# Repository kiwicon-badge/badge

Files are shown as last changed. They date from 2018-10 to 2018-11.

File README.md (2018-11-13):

# Kiwicon Intro to Badge Hacking

This repo is to host the instructions and code for the Kiwicon 2038 Intro to Badge Hacking course (https://www.kiwicon.org/the-con/training/intro-to-badge-hacking/).

## Welcome!

First up, welcome to the course :D

I hope that today is enjoyable and that you leave having gained skills and knowledge you can put to good use.

Learning the basics of electronics is a great skill. You may use this in the future to deconstructe IOT devices, build your own tools, or simply to fix a broken gadget. When combined with basic programming skills, this can take on a whole new level, where your imagination and, usually more importantly, budget are the only limits!

In particular, learning about how microcontrollers work is a great asset. This gives you the fundamentals for learning about more complex computers and systems. Note that, these days, a computer isn't really a single entity, it is a whole ecosystem of various smaller microcontrollers doing all sorts of functions. Your laptops itself likely has several dozen 'computers' in it, the CPU, GPU, controllers for the keyboard, touchpad, webcam, touchbar, SSD, Wi-Fi, Bluetooth... not to mention dongles. It's a great time to get a better understanding of how all these components can interact, particularly in light of recent events!

There is no fixed timeline to today. I have broken everything down into labs which we will move through, but feel free to go at your own pace! The only aim that I have for you today is to leave with a completed, working badge. So take time to make sure you understand everything and get the most out of it. If you race through everything, take the time to help out those around you or come up with some new idea you can program the badge to do, it's up to you.

Happy hacking!

## Safety / Conduct

+ In the event of a fire, leave all your gear and follow the exit signs out of the building.
+ In the event of an earthquake, go under your table. When the shaking stops, egress the building following the exit signs, and move to clear ground (up near parliament).
+ We will be working with toxic elements, i.e. lead (PB), in the solder. Do not ingest the solder and make sure you wash your hands before eating anything.
+ The solder flux may be irritating to some. If you have an issue, move to one of the tables / stations nearer the windows.
+ Soldering irons are hot! Always beware where you are putting it and make sure the cord is in a safe location where noone can trip over it.
+ If you see any hazards, let me know and we will work to minimise or remedy these.
+ We follow the [Kiwicon Code of Conduct](https://www.kiwicon.org/faq/#q9). Don't be a shitweasel! We're here to learn in a collaborative environment. Leave everything else at the door.

## Breaks / Facilities

+ Please note this is a working environment. Please keep noise down outside the conference room!
+ There is cans of Sprite in the fridge, water in the tap.
+ Toilets are in the stairwells, female toilets are to the left just outside the door, males to the left on the other side of the single lift. Ask for an access card before you leave, as the stairwell doors are locked. If you get locked out without a card, go to the ground floor and take the lift back up to level 4.
+ We will take regular breaks, but if you have something to do, feel free to bounce in and out as needed.

## Course Labs

+ Electrical Circuits - https://github.com/kiwicon-badge/badge/tree/master/lab-01
+ Microcontrollers - https://github.com/kiwicon-badge/badge/tree/master/lab-02
+ Loading a Program - https://github.com/kiwicon-badge/badge/tree/master/lab-03
+ Soldering - https://github.com/kiwicon-badge/badge/tree/master/lab-04
+ Badge Assembly - https://github.com/kiwicon-badge/badge/tree/master/lab-05
+ Badge Programming / Hacking - https://github.com/kiwicon-badge/badge/tree/master/lab-06

After that, if anyone is interested, we can run through PCB design using Eagle (and maybe Fritzing).

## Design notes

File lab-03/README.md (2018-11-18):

## Loading a Program

The Attiny13a is a fairly limited device, with only 1024 bytes of flash storage in which to store your program, and 64 bytes of RAM (it also has 64 bytes of EEPROM, but we won't be using that today). However, it is still a great platform to learn with and, as a quick web search shows, what you can do with it may only limited by your imagination.

In this lab, we will run through how to use the Arduino IDE and the USBAsp programmer to create and upload new code to the device. (If we're running on schedule, we'll also use the command line tools available.)

Annoyingly, USBAsp devices number their pins different to what is used on microcontrollers (this caused me a LOT of frustration at one point). Instead of starting on one side and going around, the pinouts jump from side to side:
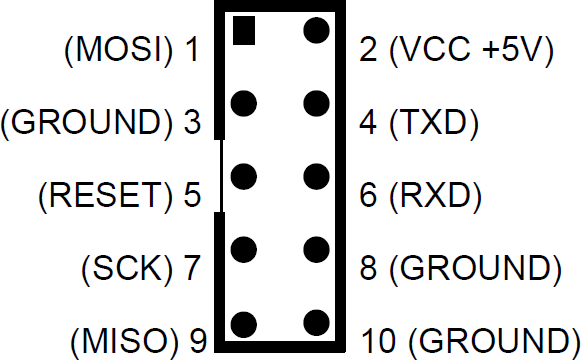
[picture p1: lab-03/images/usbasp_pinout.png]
USBAsp pinouts


Make sure you use the above pinouts!

### Tools

| Item &nbsp; &nbsp; &nbsp; &nbsp; &nbsp; &nbsp; &nbsp; &nbsp; &nbsp; &nbsp; &nbsp; &nbsp; &nbsp; &nbsp; &nbsp;&nbsp; &nbsp; &nbsp; &nbsp; &nbsp; &nbsp; &nbsp; &nbsp; &nbsp; &nbsp; &nbsp; &nbsp; &nbsp; &nbsp; | &nbsp; &nbsp; &nbsp; &nbsp; Count |
| --- |---:|
| USBAsp programmer | x1 |
| Female to male jumper wires | x6 |
| Laptop, with Arduino installed | x1 |
| Breadboard setup from Lab-02 | x1 |

### Instructions

0. Make sure you have your breadboard setup as per [Lab-02](https://github.com/kiwicon-badge/badge/blob/master/lab-02/README.md). Remove the battery and set it aside.
1. Make sure your Arduino IDE is installed. If you are on windows, install the drivers for the USBAsp ([download here](https://protostack.com.au/2015/01/usbasp-windows-driver-version-3-0-7/)).
2. Open the IDE settings (File->Settings) and paste the URL below in “Additional URLs for the board manager”, then click “OK”:
https://mcudude.github.io/MicroCore/package_MCUdude_MicroCore_index.json
3. Open the Boards manager (Tools->Board->Boards manager), search for and install the “MicroCore” package. This will enable programming the ATtiny13a microcontroller.
4. In tools, select the right options. Board: “ATtiny13”; Clock: “1.2MHz internal oscillator”; BOD: “Disabled”; Complier LTO: "Disabled".
5. In tools, select the "USBAsp" programmer.
6. Connect the programmer to your breadboard as per below:

7. In tools hit Burn the bootloader (actually it's not a true bootloader, just AVR fuses), you should see some LEDs flashing, if you don't encounter any problem you can go ahead.
8. Download the ["Blinky lights"](https://raw.githubusercontent.com/kiwicon-badge/badge/master/lab-03/files/attiny13a_blink.ino) sketch.
9. Upload this to the badge (Sketch -> Upload). While uploading the sketch, you should see some LEDs flashing. If the Arduino IDE doesn't throw any error you can go ahead, else ask for help.
10. The breadboard should now be drawing power via the USBAsp, so the microcontroller should be powered up and start the sketch.
11. Use the Arduino IDE to change the timeouts (i.e. the "delay(500)" wait instruction) and reupload your code to see the changes take effect.
12. Disconnect the jumpers to the USBAsp and plug in the battery.

### Additional Resources
+ https://quadmeup.com/programming-attiny85-and-attiny45-with-arduino-ide/
+ USBAsp drivers for Windows (should work on Win10) - https://protostack.com.au/2015/01/usbasp-windows-driver-version-3-0-7/

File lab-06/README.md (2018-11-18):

## Programming Your Badge

Similar to the earlier lab, you will now program the badge!

Use the following pinout when connecting the USBAsp to the badge:

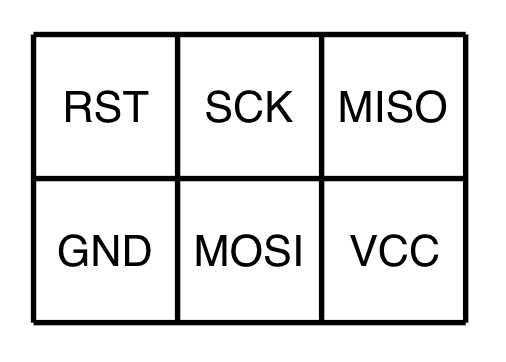
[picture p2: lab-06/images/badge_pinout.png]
USBAsp pinouts


Once final complication is that the badge uses a feature that is called "charlieplexing". As a microcontroller can have three states - input, output, and high impedance - designers can leverage this and the property of LEDs - that current can only flow forward through the component - to make up for the fact that they only have a limited number of pins. For example, the following schematic shows how to control 6 LEDs with only 3 pins:

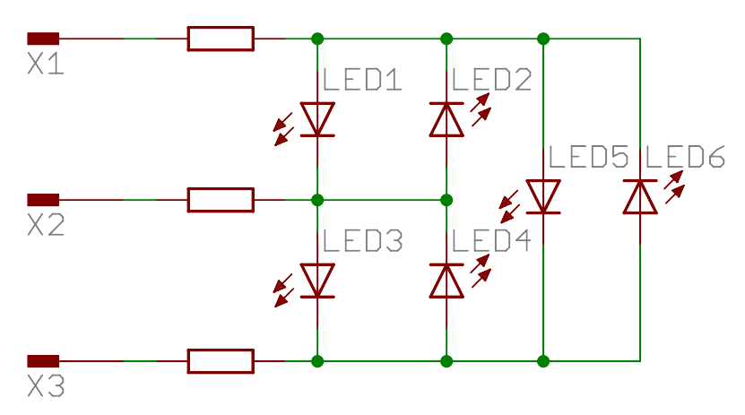
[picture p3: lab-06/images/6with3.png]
Charlieplexing


(*Rather than using charlieplexing, you can also use additional components. I have some shift registers here, which you can breadboard with if you choose.*)

In this case, the badge uses only 5 pins to control 20 LEDs individually.

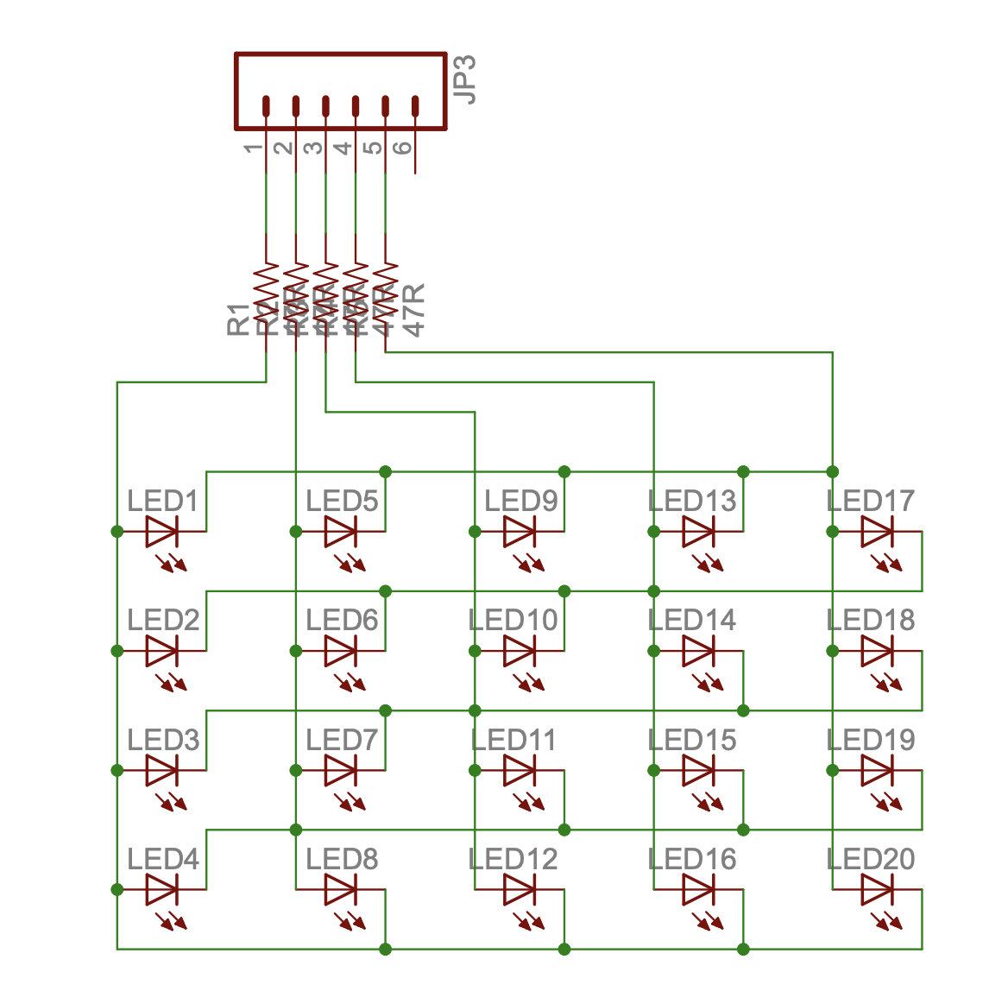
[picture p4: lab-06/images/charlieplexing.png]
Badge Charlieplexing


This means that to turn on a specific LED, you have to follow the below table:

| LED (ROW/COLUMN) | HIGH PIN | LOW PIN&nbsp; |
| ---|--:|--:|
| R1/C1 | 4 | 0 |
| R1/C2 | 3 | 0 |
| R1/C3 | 2 | 0 |
| R1/C4 | 1 | 0 |
| R2/C1 | 4 | 1 |
| R2/C2 | 3 | 1 |
| R2/C3 | 2 | 1 |
| R2/C4 | 0 | 1 |
| R3/C1 | 4 | 2 |
| R3/C2 | 3 | 2 |
| R3/C3 | 1 | 2 |
| R3/C4 | 0 | 2 |
| R4/C1 | 4 | 3 |
| R4/C2 | 2 | 3 |
| R4/C3 | 1 | 3 |
| R4/C3 | 0 | 3 |
| R5/C1 | 3 | 4 |
| R5/C2 | 2 | 4 |
| R5/C3 | 1 | 4 |
| R5/C4 | 0 | 4 |

### Tools

| Item &nbsp; &nbsp; &nbsp; &nbsp; &nbsp; &nbsp; &nbsp; &nbsp; &nbsp; &nbsp; &nbsp; &nbsp; &nbsp; &nbsp; &nbsp;&nbsp; &nbsp; &nbsp; &nbsp; &nbsp; &nbsp; &nbsp; &nbsp; &nbsp; &nbsp; &nbsp; &nbsp; &nbsp; &nbsp; | &nbsp; &nbsp; &nbsp; &nbsp; Count |
| --- |---:|
| USBAsp programmer | x1 |
| Female to male jumper wires | x6 |
| Laptop, with Arduino installed | x1 |
| Completed badge | x1 |

### Instructions

1. Remove the battery from your badge.
2. Grab the [basic code](https://raw.githubusercontent.com/kiwicon-badge/badge/master/lab-03/files/attiny13a_blink.ino) sketch.
3. Open this in your Arduino IDE, and upload this to the badge (Sketch -> Upload). While uploading the sketch, you should see some LEDs flashing. If the Arduino IDE doesn't throw any error you can go ahead, else ask for help.
4. The breadboard should now be drawing power via the USBAsp, so the microcontroller should be powered up and start the sketch.

From here on is hacking time! Come up with some new ideas and see what you can create!

### Additional Resources
+ https://en.wikipedia.org/wiki/Charlieplexing
+ lucstechblog Charlieplexing series - http://lucstechblog.blogspot.com/2017/09/charlieplexing.html

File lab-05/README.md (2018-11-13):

## Badge Assembly
The fun bit! Now you have the skills, we're going to put them all together to construct something useful. Take your time and make sure you get it right, less speed is more haste when it comes to assembly!

### Tools

| Item &nbsp; &nbsp; &nbsp; &nbsp; &nbsp; &nbsp; &nbsp; &nbsp; &nbsp; &nbsp; &nbsp; &nbsp; &nbsp; &nbsp; &nbsp;&nbsp; &nbsp; &nbsp; &nbsp; &nbsp; &nbsp; &nbsp; &nbsp; &nbsp; &nbsp; &nbsp; &nbsp; &nbsp; &nbsp; | &nbsp; &nbsp; &nbsp; &nbsp; Count |
| --- |---:|
| Soldering iron kit (wand, cradle, brass sponge) | x1 |
| Multimeter | Shared |
| Flush cutters | x1 |

### Components

| Item &nbsp; &nbsp; &nbsp; &nbsp; &nbsp; &nbsp; &nbsp; &nbsp; &nbsp; &nbsp; &nbsp; &nbsp; &nbsp; &nbsp; &nbsp;&nbsp; &nbsp; &nbsp; &nbsp; &nbsp; &nbsp; &nbsp; &nbsp; &nbsp; &nbsp; &nbsp; &nbsp; &nbsp; &nbsp; | &nbsp; &nbsp; &nbsp; &nbsp; Count |
| --- |---:|
| Badge PCB | x1 |
| Coin cell battery holder | x1 |
| Headers, male (pin) | x9 |
| Jumper | x1 |
| 100 Ohm resistor | x5 |
| Green LED | x20 |
| Solder | x1 |
| Resistor / Solid core wire | x10 |

### Instructions

You have a choice here. So far, you have practiced Through-Hole Soldering (THT), whereas the microcontroller used on the badge is an Surface Mount (SMD) component. This is somewhat trickier to solder successfully without a bit of practice! Let me know if you are game to give it a go, else I can do it for you and let you get on with the rest of the badge.

Either way, make sure your iron is nice and hot and that all your components are ready!

1. Pick up a resistor and bend the lead wires to each side of the body of the component until they are at 90 degrees to the main body, then insert this into the holes as per the image below, and press the body of the resistor until it is firmly against the front face of the PCB, then using your other hand bend the legs of the resistor outwards to hold it in place.
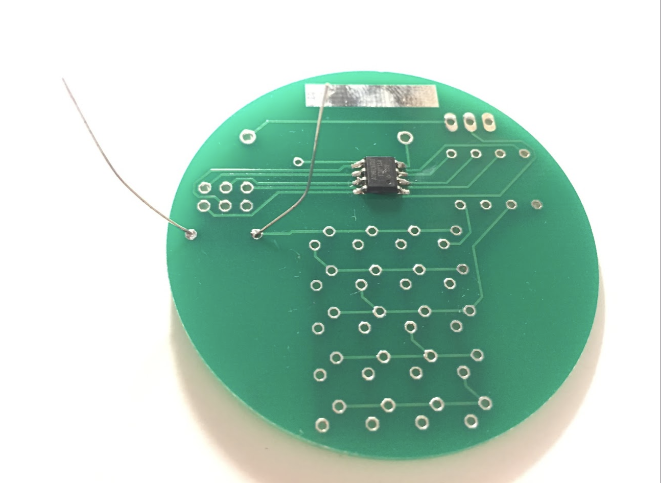
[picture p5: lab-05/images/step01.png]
First resistor

2. Solder both legs of the resistor into place.
3. Snip off the legs, about 1-1.5mm from the PCB.
4. Repeat step 1 for the next four resistors and insert them as per the image below:
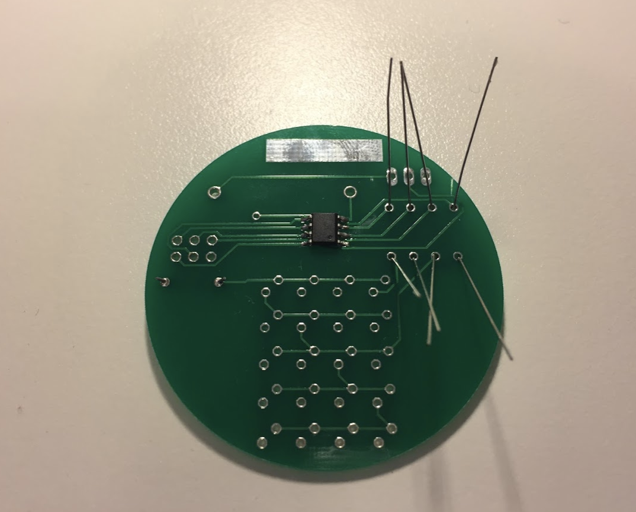
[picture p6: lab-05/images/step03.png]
Remaining resistors

5. Solder these into place and snip of the legs as per step 3.
6. Next, you will start inserting the LEDs. It is CRITICAL that you make sure that you always, always, always insert the LED legs so that the short leg (cathode / negative) is closest to the dot on the front of the PCB, as per the image below:
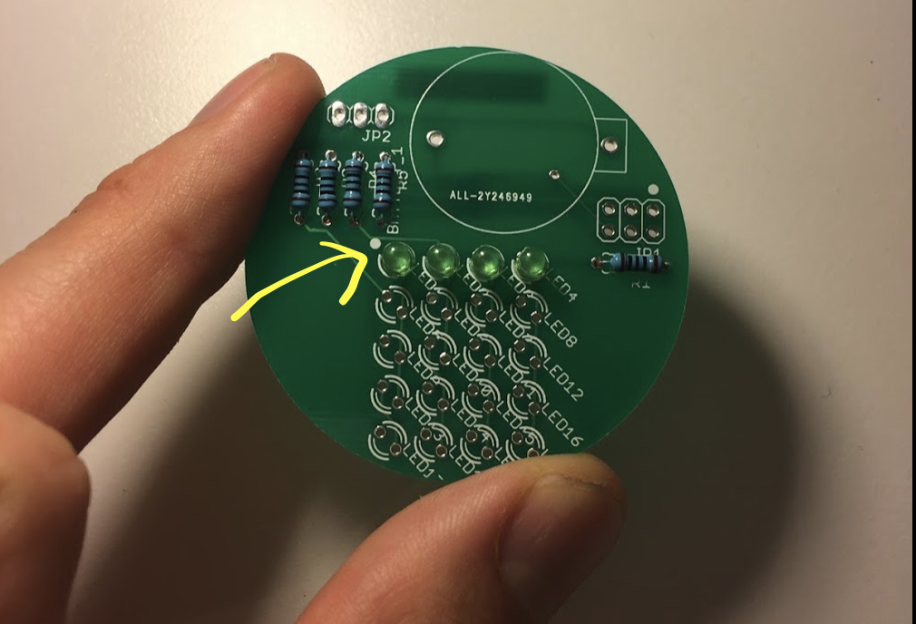
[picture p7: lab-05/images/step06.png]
Cathode dot

7. You can either insert on LED at a time (probably a good idea to start with) or insert a whole row at a time, but either way, always double check you have your LEDs oriented the correct way. Bend the legs and solder into place.
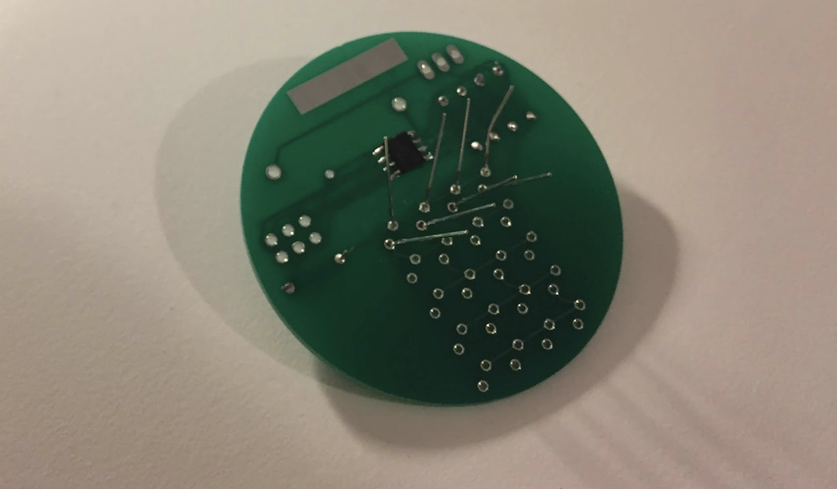
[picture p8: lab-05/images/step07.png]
Inserting LEDs

8. Once you have done a row of LEDs, give me a call to check it out. If it all looks like the below and I am happy, carry on!
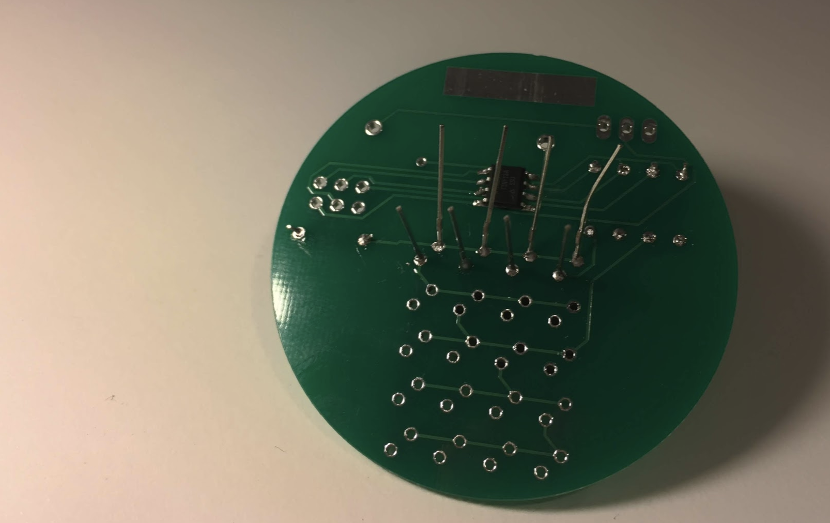
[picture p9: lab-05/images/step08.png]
Check LEDs

9. Next, you will solder in the header pins. These are a bit tricky, as you cannot simply bend the legs. If there is some bluetac handy, you can use a bit of this to hold them in place while you solder them. First do the two rows of three header pins, then do the single row of three.
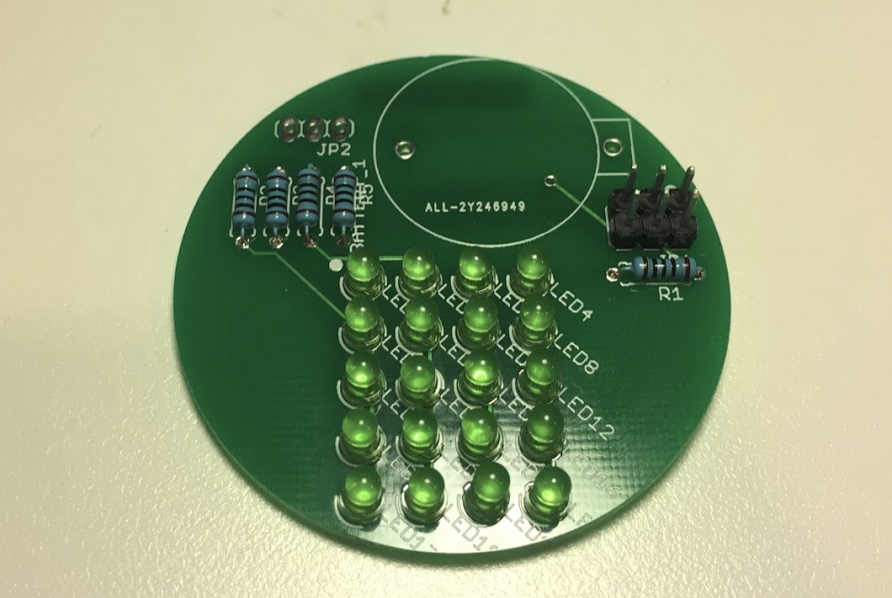
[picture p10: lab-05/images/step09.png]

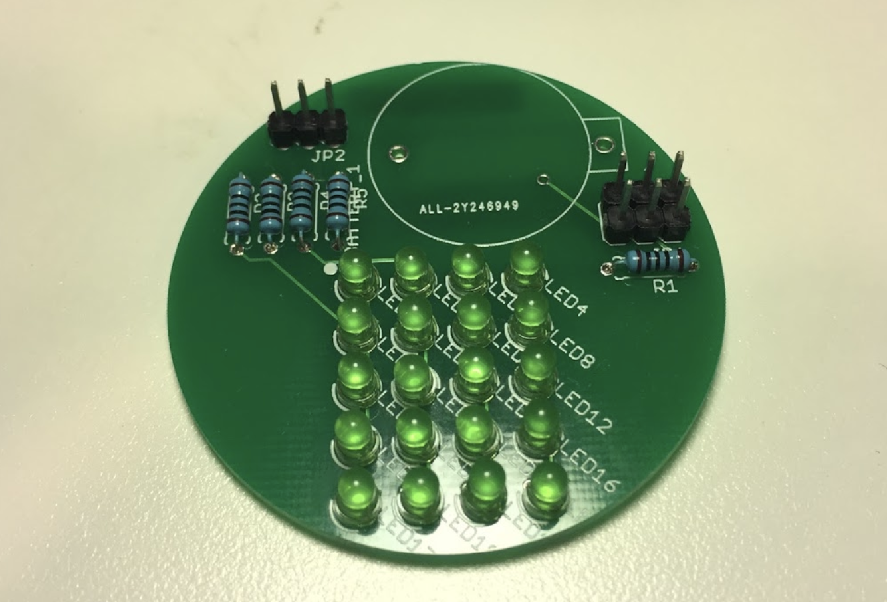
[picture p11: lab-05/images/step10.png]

10. Similar to the header pins, the battery holder is a bit fiddly. Use some bluetac to hold it in place if it is available. If not, you will get there ;) The pins are a bit larger, so may take a bit more heat. Try putting the soldering iron on the holder pins for a bit before you then also touch the PCB pads.
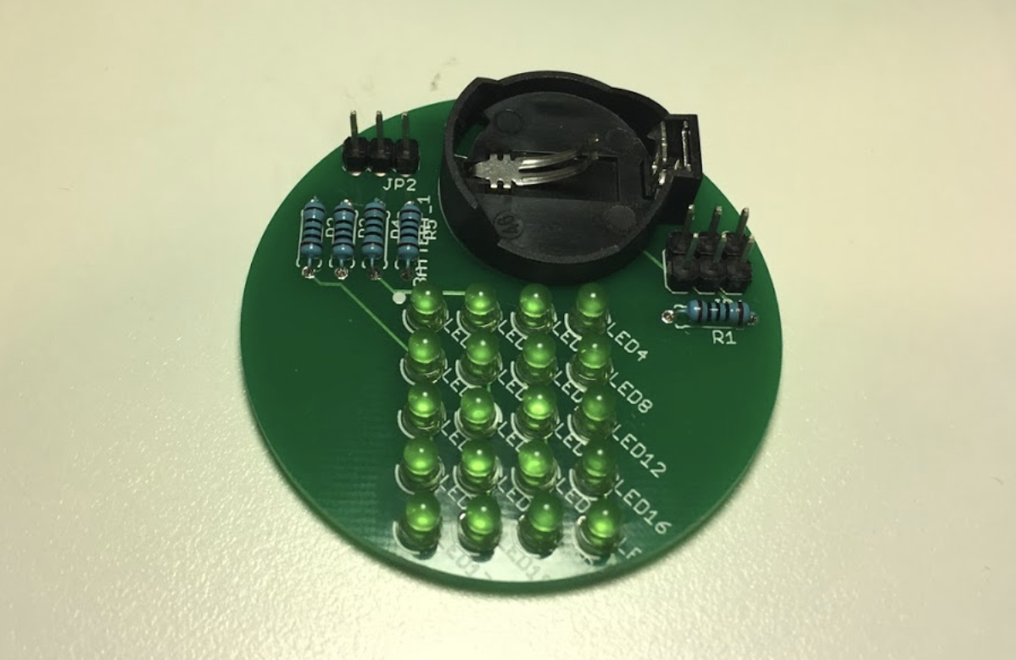
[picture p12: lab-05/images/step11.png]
Battery holder

11. You are done! The next step is to program it!
You're done

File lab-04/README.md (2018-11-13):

## Soldering
Now you have built some circuits using a breadboard, lets learn how to make something more permanent using solder to weld components together.

Soldering is a key skill when working with electronics. However, the only way to become skilled at soldering is to practice!

*Note:*

+ *Soldering irons are hot! Always be aware of where you soldering iron is, especially the tip. Never lay it on the table, always put it back in the holder.*
+ *Solder and solder flux creates fumes which may irritate. Alway solder in a well ventilated area.*
+ *Solder contains lead (Pb), a toxic substance. Do not ingest it! Wash your hands after soldering and make sure you do not hold components in your mouth to prevent this!*

### Tools

| Item &nbsp; &nbsp; &nbsp; &nbsp; &nbsp; &nbsp; &nbsp; &nbsp; &nbsp; &nbsp; &nbsp; &nbsp; &nbsp; &nbsp; &nbsp;&nbsp; &nbsp; &nbsp; &nbsp; &nbsp; &nbsp; &nbsp; &nbsp; &nbsp; &nbsp; &nbsp; &nbsp; &nbsp; &nbsp; | &nbsp; &nbsp; &nbsp; &nbsp; Count |
| --- |---:|
| Soldering iron kit (wand, cradle, brass sponge) | x1 |
| Multimeter | Shared |
| Flush cutters | x1 |

### Components

| Item &nbsp; &nbsp; &nbsp; &nbsp; &nbsp; &nbsp; &nbsp; &nbsp; &nbsp; &nbsp; &nbsp; &nbsp; &nbsp; &nbsp; &nbsp;&nbsp; &nbsp; &nbsp; &nbsp; &nbsp; &nbsp; &nbsp; &nbsp; &nbsp; &nbsp; &nbsp; &nbsp; &nbsp; &nbsp; | &nbsp; &nbsp; &nbsp; &nbsp; Count |
| --- |---:|
| PCB Perfboard | x1 |
| Solder | x1 |
| Resistor / Solid core wire | x10 |

### Instructions
1. Plug in your soldering iron, set it to 325 degrees, and place it on the cradle to warm up. Make sure you are always aware of you iron and its cable!
2. Prep your first item to solder. Insert each leg of a resistor through a hole on the perfboard, then bend the wires away from the component, which will hold it in place, like the image below (*well not exaclty, I forgot to take a pic using a perfboard, so I used a badge example instead*):
Bending legs
3. Place the perfboard on the table or stick it in some bluetac to hold it in place.
4. Test your soldering irons temperature by gently touching the end of the solder to the iron, about 1-2mm back from the tip. This is the hottest part of the iron, not the tip. If the solder melts, you're good to go. This is called "tinning" the iron. Wipe off the excess solder using the brass sponge.
5. Gently press the side of your soldering iron, about 1-2mm back from the tip, against the leg of the resistor, also touching the metal pad of the perfboard hole. Let both heat up for a couple of seconds, then gently touch the end of the solder to the soldering iron near where it touches the component. Refer to [this video](https://raw.githubusercontent.com/kiwicon-badge/badge/master/lab-04/images/soldering.mov) for an example.
6. The solder wire should melt and wick into the gap between the resistor and the perfboard. When it does, pull away the solderfirst, then the iron.
7. Et voila! You've made your first solder joint.

Once you have done a bunch, give me a yell to come check out your handy work.

*Note:
+ You are not trying to wipe solder from the iron onto the components. You should instead heat the components up and let capilliary action work its magic. As long as everything is up to temperature, solder will quickly wick into the joint.
+ Use the side of the tip (aka the sweet spot), not the very tip of the iron. This is the hottest part and works the best to quickly get the components up to temperature. That said, if you need to get into a tight spot or are doing SMD work on small traces, use the tip,.
+ Aim to heat both the pad and the part you want to solder evenly and at the same time. Be aware that larger components will take more heat, so you will have to press the iron against those first before also touching the pad.
+ Regularly tin your soldering iron and clean it off in the brass sponge. A clean tip works much better than a dirty one!*

### Additional Resources
+ https://learn.sparkfun.com/tutorials/how-to-solder-through-hole-soldering/all
+ EEVblog #180 - Soldering Tutorial Part 1 - Tools https://www.youtube.com/watch?v=J5Sb21qbpEQ
+ EEVblog #183 - Soldering Tutorial Part 2 https://www.youtube.com/watch?v=fYz5nIHH0iY

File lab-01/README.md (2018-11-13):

## Electrical Circuits

In the first part of the course, we are going to learn a bit about the laws which govern how electricity behaves and about the components we will utilise to put it to work.

Electrical circuits are all about electrons (the ‘charge’) flowing through a conductive path (the 'current') from a low potential area to a high potential area (the ‘voltage’). There are many components we can use to modify how that charge flows, including interrupting it (‘switches’), limiting it (‘resistors’), storing it (‘capacitors’), and transforming its energy to another form (‘LEDs’).

The key equation to learn which governs how this charge moves is:
```voltage = current * resistance (V = IR)```

In the first lab, we will use a battery (changing chemical energy to potential energy) and some simple components to create some simple circuit and measure the differences in voltage and current at various points and learn the differences in between series and parallel circuits.

### Tools

| Item &nbsp; &nbsp; &nbsp; &nbsp; &nbsp; &nbsp; &nbsp; &nbsp; &nbsp; &nbsp; &nbsp; &nbsp; &nbsp; &nbsp; &nbsp;&nbsp; &nbsp; &nbsp; &nbsp; &nbsp; &nbsp; &nbsp; &nbsp; &nbsp; &nbsp; &nbsp; &nbsp; &nbsp; &nbsp; | &nbsp; &nbsp; &nbsp; &nbsp; Count |
| --------------------------------- |-------:|
| Multimeter                        | Shared |

### Components

| Item &nbsp; &nbsp; &nbsp; &nbsp; &nbsp; &nbsp; &nbsp; &nbsp; &nbsp; &nbsp; &nbsp; &nbsp; &nbsp; &nbsp; &nbsp;&nbsp; &nbsp; &nbsp; &nbsp; &nbsp; &nbsp; &nbsp; &nbsp; &nbsp; &nbsp; &nbsp; &nbsp; &nbsp; &nbsp; | &nbsp; &nbsp; &nbsp; &nbsp; Count |
| --------------------------------- |-------:|
| Breadboard                        |     x1 |
| LED                               |     x2 |
| 100 Ohm resister                  |     x2 |
| Button battery holder             |     x1 |
| Button battery (CR2025 or CR2032) |     x1 |
| Jumper wires                      |     x2 |

### Instructions

1. Using your breadboard as the base, create the following circuit.
![Basic Circuit](https://raw.githubusercontent.com/kiwicon-badge/badge/master/lab-01/images/led01-breadboard.png)
![Basic Circuit](https://raw.githubusercontent.com/kiwicon-badge/badge/master/lab-01/images/led01-photo.png)
2. Put the multimeter into `Voltage - DC` mode and measure the voltage across various components (touch each leg).
3. Add the second resistor to the circuit in series (i.e. one after the other in a circuit) as per the diagram below. Observe the changes in the LED brightness and use the multimeter to measure the differing voltage drops.
![Basic Circuit](https://raw.githubusercontent.com/kiwicon-badge/badge/master/lab-01/images/led02-breadboard.png)
4. Add the second resistor to the circuit in parallel (i.e. both starting at the same point and finishing at the same point). Observe the changes in the LED brightness and use the multimeter to measure the differing voltage drops.
![Basic Circuit](https://raw.githubusercontent.com/kiwicon-badge/badge/master/lab-01/images/led03-breadboard.png)

### Additional Resources
+ https://www.electronics-tutorials.ws/
+ https://learn.sparkfun.com/tutorials/how-to-use-a-breadboard
+ https://learn.sparkfun.com/tutorials/voltage-current-resistance-and-ohms-law
+ https://learn.sparkfun.com/tutorials/what-is-a-circuit

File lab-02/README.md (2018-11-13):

## Microcontrollers
This lab will teach the basics of constructing a circuit which includes a microcontroller.

Microcontrollers are cheap devices which allow you to introduce programmable behaviour to a system. This can be used for pretty much anything you can imagine, from simply telling a LED to blink, to controlling the lights in your home, and even to creating a conference badge of blinky LEDs. Of course, you can do more than turning lights on and off, too ;)

Microcontrollers generally have several major components:
+ Central Processing Unit (CPU)
+ Random Access Memory (RAM)
+ Read Only Memory (ROM)
+ Input/Output Ports (IO ports)
+ Timers and Counters
+ Interrupt Controls
+ Analog to digital converters / Digital analog converters (maybe)

The badge uses the relatively simple and inexpensive Atmel AVR Attiny13A chip. The Attiny family of microcontrollers includes a range of minimal very low power devices which are great for small projects. Other common microcontrollers you may come across include the Atmel Atmega range, commonly used in Arduino devices.

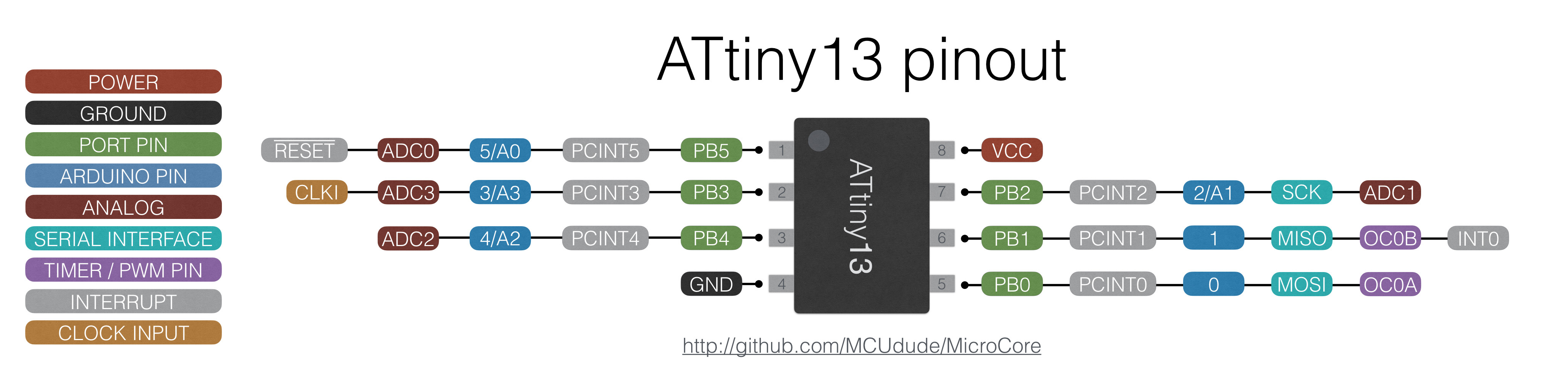
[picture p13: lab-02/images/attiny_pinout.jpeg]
ATtiny13A pinouts


IO ports are what is called tri-state. They can be set to in (current sink / 0), out (current source / 1), or high impedance (no in or out, effectively removed from the circuit). In the pinout diagram above, the IO pins themselves are given various names, depending on the functions they can be used for. All you need to know for today are the green names (PB0-5, VCC, and GND). When dealing with microcontrollers, VCC is another name for positive, i.e. connect the positive side of the battery to this pin.

### Components
| Item &nbsp; &nbsp; &nbsp; &nbsp; &nbsp; &nbsp; &nbsp; &nbsp; &nbsp; &nbsp; &nbsp; &nbsp; &nbsp; &nbsp; &nbsp;&nbsp; &nbsp; &nbsp; &nbsp; &nbsp; &nbsp; &nbsp; &nbsp; &nbsp; &nbsp; &nbsp; &nbsp; &nbsp; &nbsp; | &nbsp; &nbsp; &nbsp; &nbsp; Count |
| --- |---:|
| Breadboard | x1 |
| LED | x2 |
| 100 Ohm resister | x2 |
| Button battery holder | x1 |
| Button battery (CR2025 or CR2032) | x1 |
| Jumper wires | x3 |

### Instructions
1. Assemble the components into a circuit based on the following diagram (note: UC dot to the left):
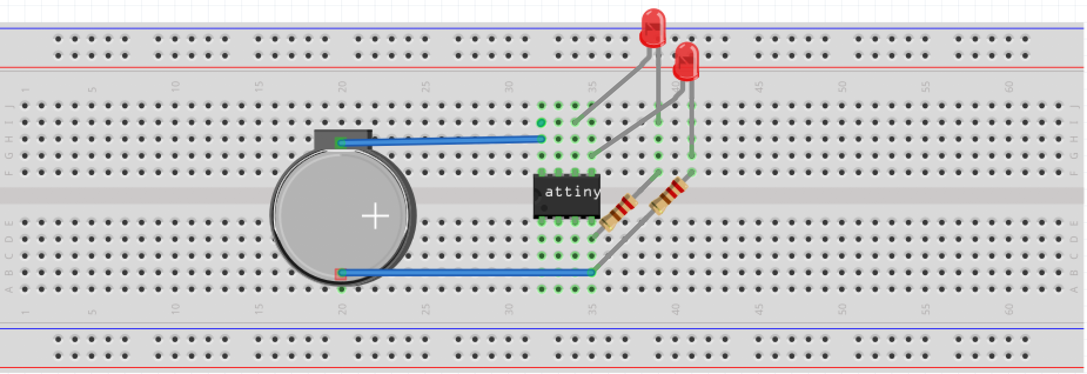
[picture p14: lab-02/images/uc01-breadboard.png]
UC and LED circuit

2. Once all is connected, insert the battery into the battery holder. Make sure the flat side with writing is up.
3. All going well, the preprogrammed microcontroller should alternately flash both LEDs (as long as I have had time to upload [the code](https://raw.githubusercontent.com/kiwicon-badge/badge/master/lab-02/files/attiny13a_blink.ino), if not, we will get to that in a minute).

### Additional References

+ https://learn.sparkfun.com/tutorials/logic-levels/all
+ https://en.wikipedia.org/wiki/ATtiny_microcontroller_comparison_chart
+ https://www.microchip.com/wwwproducts/en/ATtiny13A

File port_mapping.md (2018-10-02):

# Port States

```DDR PORT
  0    0  - input, high impedance
  0    1  - input, pulled up
  1    0  - output, driven low
  1    1  - output, driven high
```

# LED to Pin Mapping

```LED        Pin (H/L)
  LED R1C1 = 4H0L
  LED R1C2 = 3H0L
  LED R1C3 = 2H0L
  LED R1C4 = 1H0L

  LED R2C1 = 4H1L
  LED R2C2 = 3H1L
  LED R2C3 = 2H1L
  LED R2C4 = 0H1L

  LED R3C1 = 4H2L
  LED R3C2 = 3H2L
  LED R3C3 = 1H2L
  LED R3C4 = 0H2L

  LED R4C1 = 4H3L
  LED R4C2 = 2H3L
  LED R4C3 = 1H3L
  LED R4C3 = 0H3L

  LED R5C1 = 3H4L
  LED R5C2 = 2H4L
  LED R5C3 = 1H4L
  LED R5C4 = 0H4L
```

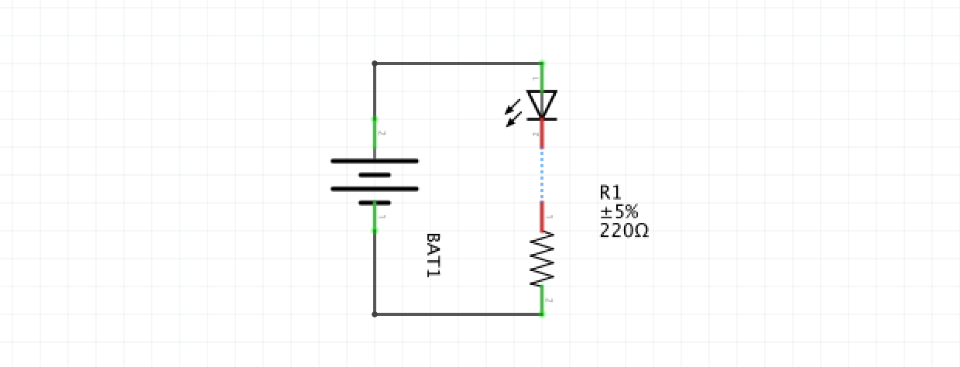
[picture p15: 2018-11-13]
lab-01/images/led-schematic.png

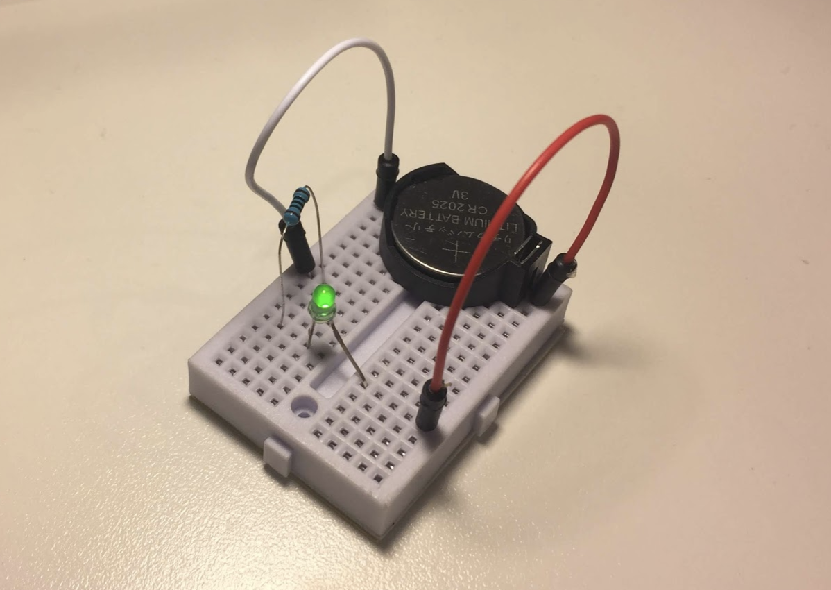
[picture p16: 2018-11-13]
lab-01/images/led01-photo.png

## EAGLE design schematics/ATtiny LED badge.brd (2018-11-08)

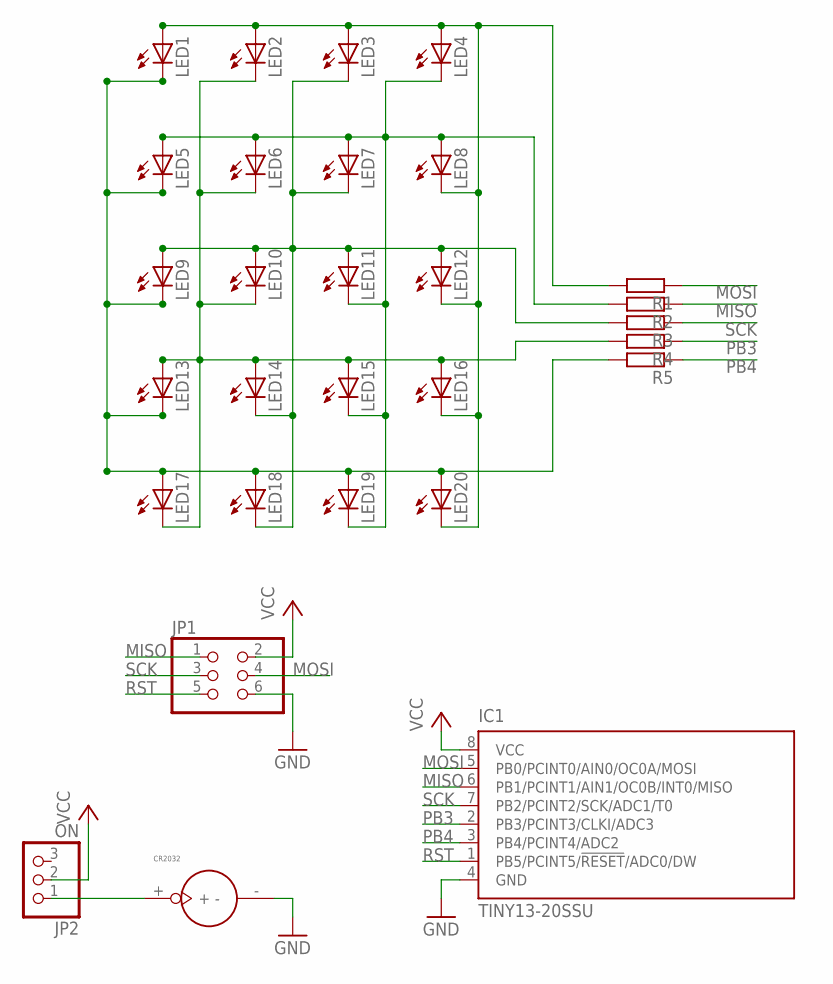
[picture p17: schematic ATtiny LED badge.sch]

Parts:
CR2032: BATTERY_1236_C
IC1: TINY13-20SSU; 8S1
JP1: PINHD-2X3; 2X03
JP2: ON; 1X03
LED1, LED2, LED3, LED4, LED5, LED6, LED7, LED8, LED9, LED10, LED11, LED12, LED13, LED14, LED15, LED16, LED17, LED18, LED19, LED20: LED3MM
R1, R2, R3, R4, R5: R-EU_0207/7; 0207/7

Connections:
GND: CR2032.-, IC1.4 (GND), JP1.6
MISO: IC1.6 (PB1/PCINT1/AIN1/OC0B/INT0/MISO), JP1.1, R2.1
MOSI: IC1.5 (PB0/PCINT0/AIN0/OC0A/MOSI), JP1.4, R1.1
unnamed: LED1.A, LED2.A, LED3.A, LED4.A, LED8.K (C), LED12.K (C), LED16.K (C), LED20.K (C), R1.2
unnamed: LED4.K (C), LED5.A, LED6.A, LED7.A, LED8.A, LED11.K (C), LED15.K (C), LED19.K (C), R2.2
unnamed: LED3.K (C), LED7.K (C), LED9.A, LED10.A, LED11.A, LED12.A, LED14.K (C), LED18.K (C), R3.2
unnamed: LED2.K (C), LED6.K (C), LED10.K (C), LED13.A, LED14.A, LED15.A, LED16.A, LED17.K (C), R4.2
unnamed: LED1.K (C), LED5.K (C), LED9.K (C), LED13.K (C), LED17.A, LED18.A, LED19.A, LED20.A, R5.2
unnamed: CR2032.+, JP2.1
PB3: IC1.2 (PB3/PCINT3/CLKI/ADC3), R4.1
PB4: IC1.3 (PB4/PCINT4/ADC2), R5.1
RST: IC1.1 (PB5/PCINT5/!RESET!/ADC0/DW), JP1.5
SCK: IC1.7 (PB2/PCINT2/SCK/ADC1/T0), JP1.3, R3.1
VCC: IC1.8 (VCC), JP1.2, JP2.2

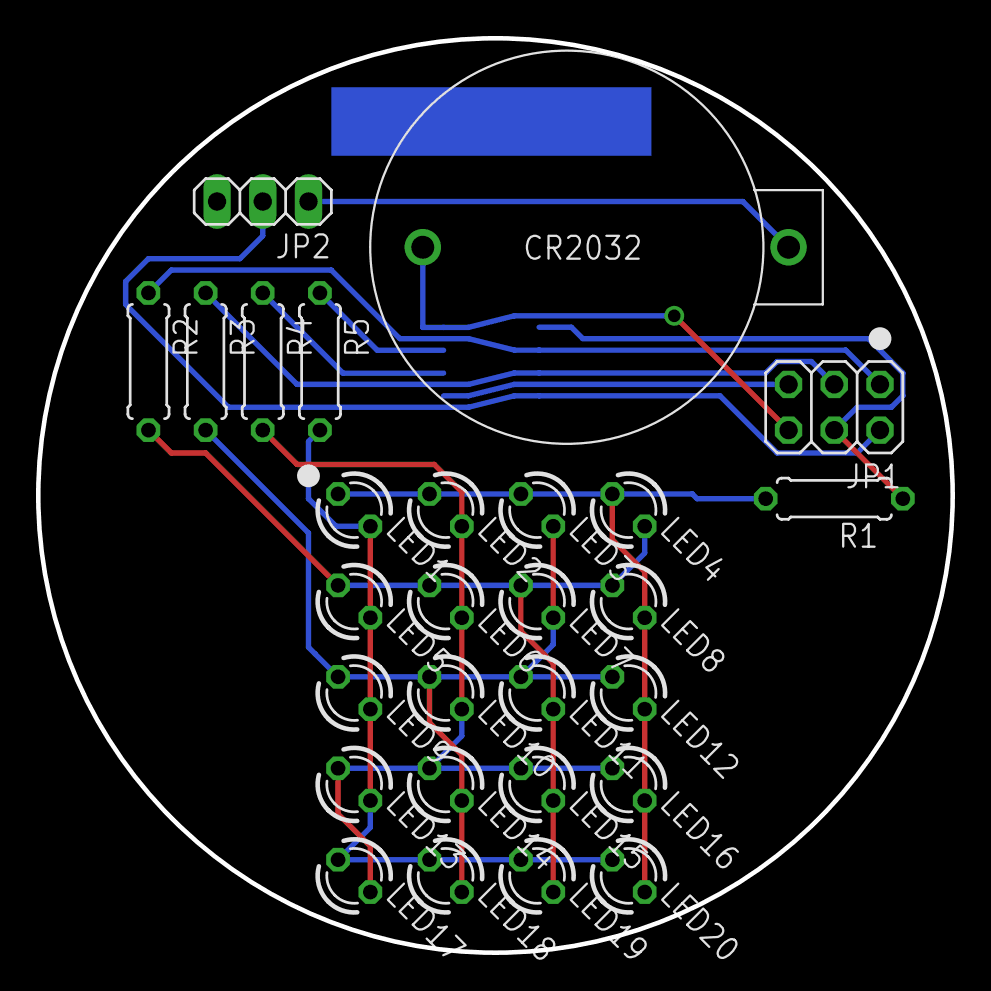
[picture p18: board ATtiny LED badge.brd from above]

Board: 2 copper layers, 50.8 x 50.8 mm, 29 parts (1 on the bottom side), 14 nets.

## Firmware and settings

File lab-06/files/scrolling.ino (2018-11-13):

#define DISPLAY_STRING "KIWICON 2038"

#ifndef __AVR_ATtiny13__
	#error Select ATtiny13A from Arduino Tools menu.
#endif

// Character set
PROGMEM const unsigned long alphabet[] = {
	0b00000000000000000000,	// 32 space
	0b00100010001000000010,	// 33 !
	0b01010101000000000000,	// 34 "
	0b01101111011011110110,	// 35 #
	0b01101000010000101100,	// 36 $
	0b00001001001001001001,	// 37 %
	0b01001000010110100101,	// 38 &
	0b00100010000000000000,	// 39 '
	0b00100100010001000010,	// 40 (
	0b01000010001000100100,	// 41 )
	0b01010010010100000000,	// 42 *
	0b00000000010011100100,	// 43 +
	0b00000000000000100100,	// 44 ,
	0b00000000011000000000,	// 45 -
	0b00000000000000000100,	// 46 .
	0b00010011011011001000,	// 47 /
	0b01101101101110010110,	// 48 0
	0b00100110001000100111,	// 49 1
	0b11100001011010001111,	// 50 2
	0b11100001011000011110,	// 51 3
	0b00100110101011110010,	// 52 4
	0b11111000111000011110,	// 53 5
	0b01101000111010010110,	// 54 6
	0b11110001001001001000,	// 55 7
	0b01101001011010010110,	// 56 8
	0b01101001011100010110,	// 57 9
	0b00000100000001000000,	// 58 :
	0b00000100000001001000,	// 59 ;
	0b00110110110001100011,	// 60 <
	0b00001111000011110000,	// 61 =
	0b11000110001101101100,	// 62 >
	0b01001010001001000100,	// 63 ?
	0b01101011101110000110,	// 64 @
	0b01101001111110011001,	// 65 A
	0b11101001111010011110,	// 66 B
	0b01111000100010000111,	// 67 C
	0b11101001100110011110,	// 68 D
	0b11111000111010001111,	// 69 E
	0b11111000111010001000,	// 70 F
	0b01111000101110010110,	// 71 G
	0b10011001111110011001,	// 72 H
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
};

const int displayWidth = 4;
const int displayHeight = 5;

// between pixels
const unsigned int timeout = 150;

const char PROGMEM displayString[] = DISPLAY_STRING;
const byte stringLength = sizeof(displayString);

// The offset of our string in the display
int offset = 0;
unsigned long lastMillis = 0;
unsigned long currentMillis = 0;

// render the string on the given offset
void renderString(int offset) {
  for(byte index=0; index< (stringLength-1); index++){
  	uint8_t pos = pgm_read_byte(&displayString[index]) - 32;
  	unsigned long gfx = pgm_read_dword(&alphabet[pos]);
    renderCharacter(gfx, offset - index * (displayWidth + 1));
  }
}


void renderCharacter(unsigned long graphic, int charOffset) {
  if (charOffset <= -displayWidth || charOffset > displayWidth) {
    // off the 'screen' nothing to do
    return;
  }

  for (byte y = 0; y < displayHeight; y++) {
    for (byte x = 0; x < displayWidth; x++) {
      // 3 - x to reverse order
      setPixel(3 - x - charOffset, y, graphic & 0x1);
      graphic = graphic >> 1;
    }
  }
}

// light a pixel at the given coordinates
void setPixel(byte x, byte y, boolean ledStatus) {
  if (x < displayWidth) {
    if (y <= x) {
      x++;
    }
    setLed(4-x, 4-y, ledStatus);
  }
}

// turn on the pins to light a LED
void setLed(byte vin, byte gnd, boolean ledStatus) {
  delayMicroseconds(500);
  
  if(ledStatus) {
    DDRB = (0x01 << vin) | (0x01 << gnd);
    PORTB = 0x01 << vin;
  }
  else {
    DDRB = 0x00;
  }
}

void setup() {
}

void loop() {
  currentMillis = millis();

  renderString(offset);

  if (currentMillis - lastMillis > timeout) {
    lastMillis = currentMillis;
    // shift string over one "pixel"
    offset++;
    // if it's past the length of the string, start over from the beginning
    if (offset > (stringLength-1) * (displayWidth + 1)) {
      offset = -displayWidth;
    }
  }
}

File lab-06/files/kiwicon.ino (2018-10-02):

/*
  DDR PORT
  0    0  - input, high impedance
  0    1  - input, pulled up
  1    0  - output, driven low
  1    1  - output, driven high

  LED R1C1 = 4H0L
  LED R1C2 = 3H0L
  LED R1C3 = 2H0L
  LED R1C4 = 1H0L

  LED R2C1 = 4H1L
  LED R2C2 = 3H1L
  LED R2C3 = 2H1L
  LED R2C4 = 0H1L

  LED R3C1 = 4H2L
  LED R3C2 = 3H2L
  LED R3C3 = 1H2L
  LED R3C4 = 0H2L

  LED R4C1 = 4H3L
  LED R4C2 = 2H3L
  LED R4C3 = 1H3L
  LED R4C3 = 0H3L

  LED R5C1 = 3H4L
  LED R5C2 = 2H4L
  LED R5C3 = 1H4L
  LED R5C4 = 0H4L
*/

void writetoled(int high, int low) {
  pinMode(high, OUTPUT);
  pinMode(low, OUTPUT);
  digitalWrite(high, HIGH);
  digitalWrite(low, LOW);
  delayMicroseconds(10);
  digitalWrite(high, LOW);
  pinMode(high, INPUT);
  pinMode(low, INPUT);
  delayMicroseconds(10);
}

void displayCharacterBlock(long character) {
  char counter, high, low, row, skip;

  for (counter = 0; counter < 100; counter++) {
    for (low = 0; low < 5; low++) {
      row = character >> ((4 - low) * 4);
      skip = 0;
      for (high = 4; high >= 0; high--) {
        if (low == high) {
          skip = 1;
          continue;
        }
        if (row >> ((high - 1) + skip) & 0x01) {
          writetoled(high, low);
        } else {
          delayMicroseconds(20);
        }
      }
    }
  }
}

// the setup function runs once when you press reset or power the board
void setup() {
  
}

// the loop function runs over and over again forever
void loop() {
  int counter;
  
  // Legal characters for MESSAGE_STRING include A-Z, '!', ' ' (space), and '#' (block).
  char MESSAGE[] = "KIWICON";
  
  for (counter = 0; counter < sizeof(MESSAGE); counter++) {
    long character;

    character = (long) MESSAGE[counter];

    if (character == 'A') character = 0b01101001111110011001;
    if (character == 'B') character = 0b01101001111110011001;
    if (character == 'C') character = 0b01111000100010000111;
    if (character == 'D') character = 0b11101001100110011110;
    if (character == 'E') character = 0b11111000111010001111;
//  if (character == 'F') character = 0b11111000111010001000;
//  if (character == 'G') character = 0b01111000101110010110;
//  if (character == 'H') character = 0b10011001111110011001;
    if (character == 'I') character = 0b01110010001000100111;
//  if (character == 'J') character = 0b01110010001010100100;
    if (character == 'K') character = 0b10011010110010101001;
//  if (character == 'L') character = 0b10001000100010001111;
//  if (character == 'M') character = 0b10011111111110011001;
    if (character == 'N') character = 0b10011101101110011001;
    if (character == 'O') character = 0b01101001100110010110;
//  if (character == 'P') character = 0b11101001111010001000;
//  if (character == 'Q') character = 0b01101001101101100001;
//  if (character == 'R') character = 0b11101001111010101001;
//  if (character == 'S') character = 0b11111000111100011111;
//  if (character == 'T') character = 0b01110010001000100010;
//  if (character == 'U') character = 0b10011001100110010110;
//  if (character == 'V') character = 0b10011001100110100100;
    if (character == 'W') character = 0b10011001111111110110;
//  if (character == 'X') character = 0b10011001011010011001;
//  if (character == 'Y') character = 0b10011001011000101100;
//  if (character == 'Z') character = 0b11110001001001001111;
    if (character == '!') character = 0b01000100010000000100;
    if (character == '#') character = 0b11111111111111111111;
    if (character == ' ') character = 0b00000000000000000000;
    
    displayCharacterBlock(character);
  }
}
